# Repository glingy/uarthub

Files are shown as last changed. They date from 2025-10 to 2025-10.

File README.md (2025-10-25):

# UART Hub

This is a 6-port "null modem cable". There are six 4-signal UART channels with flow control. Each channel is connected to all six RP2040's at each USB port to allow full software configuration of which USB ports communicate on which channels. 

For example with the following configuration:
```
Channel 0: Port 0, Port 1
Channel 1: Port 0, Port 2
Channel 2: Port 1, Port 3
Channel 3: Port 1, Port 2
Channel 4: Port 0, Port 1
Channel 5: Port 0, External
```

A computer connected to USB 0 will see four USB CDC-ACM serial ports (COM ports on Windows, TTY's on Linux). They will be connected to USB 1, USB 2, USB 1, and the external pins labeled `5` respectively. Port 1 will also have four serial ports (USB 0, USB 3, USB 2, USB 0). Note that in this case there are two independent serial connections between USB 0 and 1. USB 2 will have two serial ports, USB 3 will only see one port, and USB 4 & 5 will see no serial ports. 

USB 0 will also have an additional management serial port that allows runtime configuration of which ports are associated with each channel via a terminal-based UI.

This project is not intended to work for other protocols (I2C, SPI), but the hardware should be capable of supporting I2C or SPI devices on the external pins, the RP2040 uses the same pins for I2C/SPI as it does for UART.

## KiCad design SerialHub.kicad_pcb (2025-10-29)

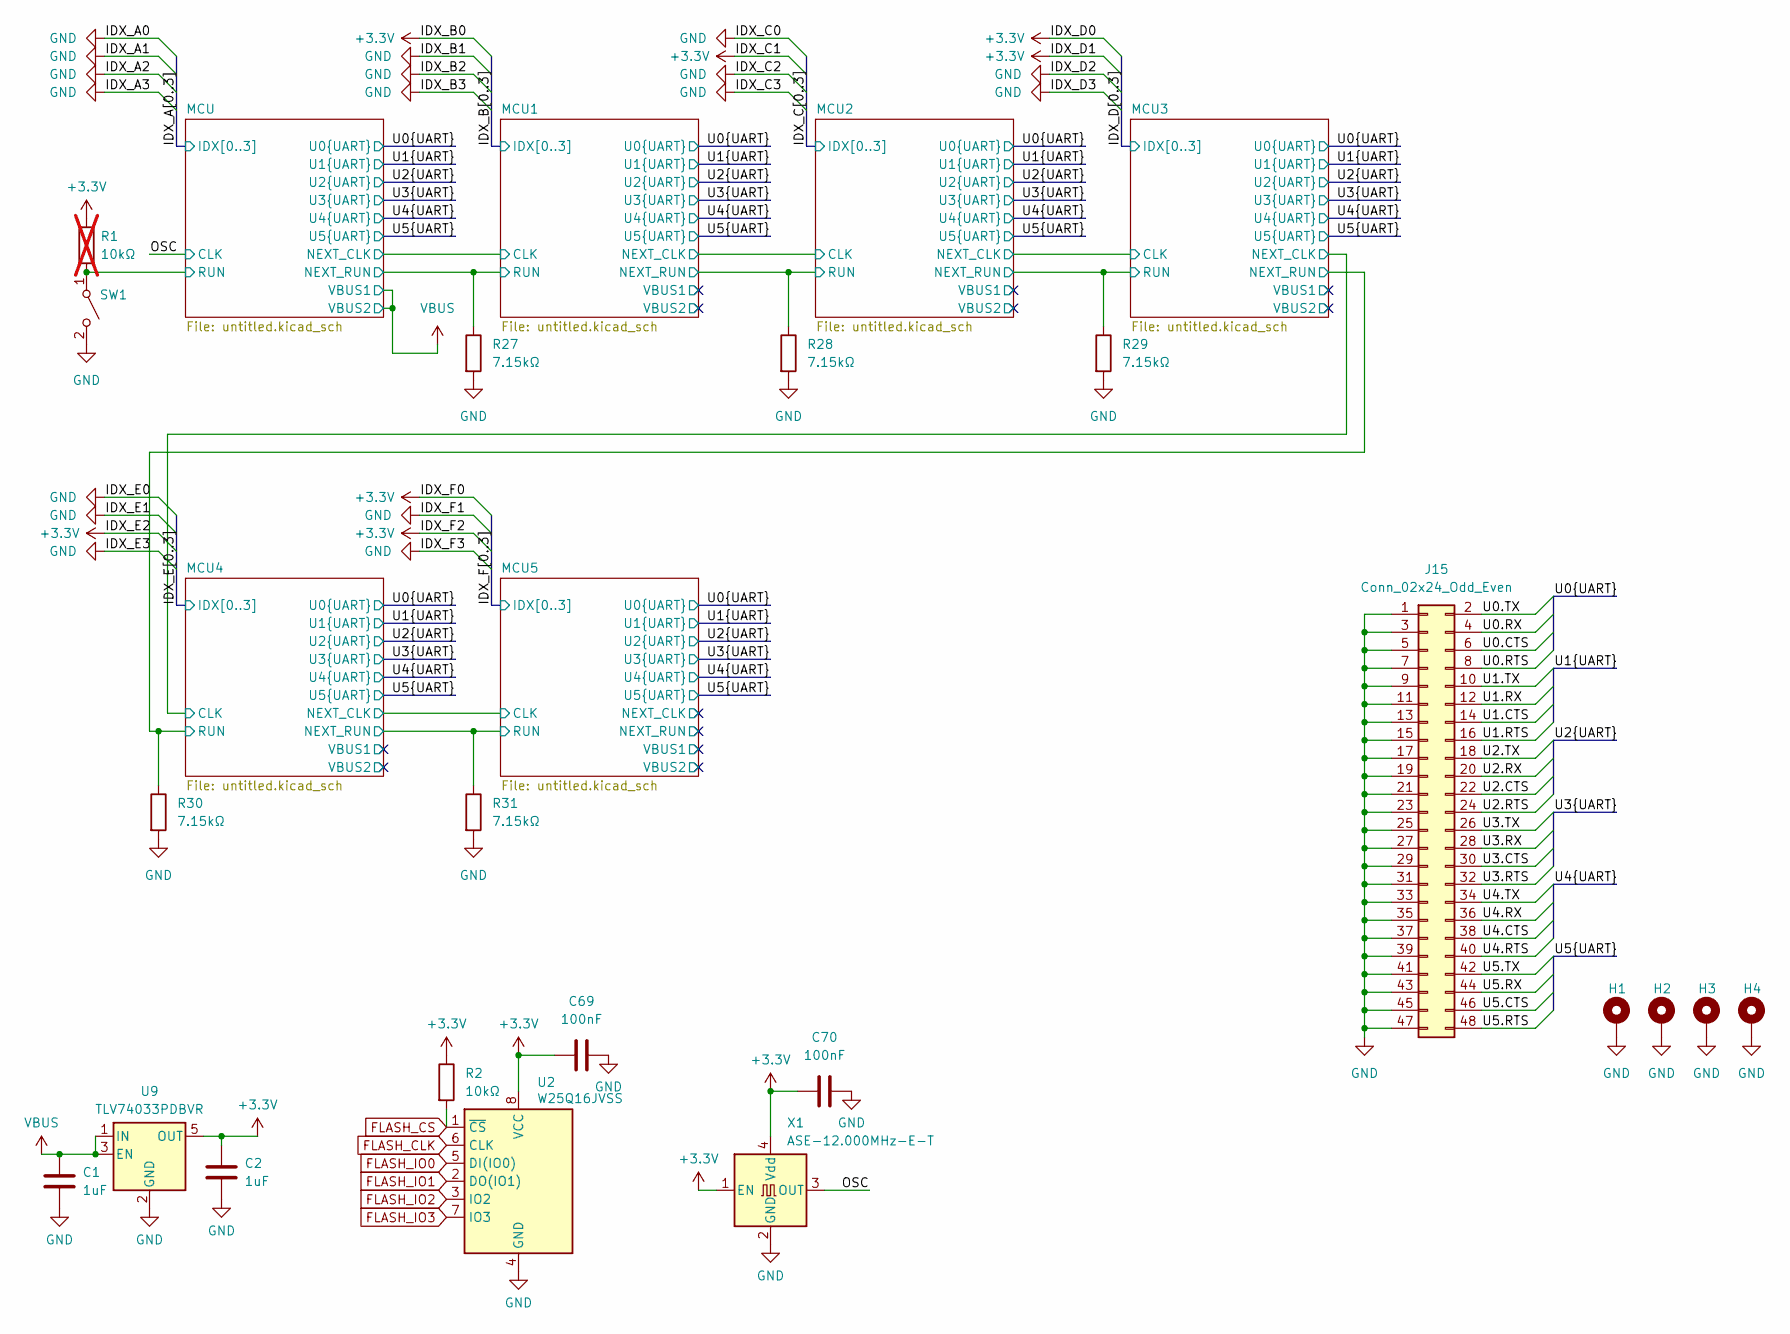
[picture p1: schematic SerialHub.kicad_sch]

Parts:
C1, C2: 1uF; C_0402_1005Metric; Digikey 399-C0402C105K9PACTUCT-ND
C69, C70: 100nF; C_0402_1005Metric; Digikey 399-C0402C105K9PACTUCT-ND
H1, H2, H3, H4: MountingHole_Pad; MountingHole_3.2mm_M3_Pad
J15: Conn_02x24_Odd_Even; PinHeader_2x24_P2.54mm_Vertical
R1: 10kΩ; R_0402_1005Metric; Digikey 311-10KJRCT-ND; not fitted
R2: 10kΩ; R_0402_1005Metric; Digikey 311-10KJRCT-ND
R27, R28, R29, R30, R31: 7.15kΩ; R_0402_1005Metric; Digikey YAG3235CT-ND
SW1: SW_SPST; SW_PUSH_6mm_H4.3mm; Digikey 2223-TS02-66-43-BK-160-LCR-D-ND
U2: W25Q16JVSS; SOIC-8_5.3x5.3mm_P1.27mm; Digikey 256-W25Q16JVSSIQTRCT-ND
U9: TLV74033PDBVR; SOT-23-5; Digikey 296-TLV74033PDBVRCT-ND
X1: ASE-12.000MHz-E-T; Oscillator_SMD_Abracon_ASE-4Pin_3.2x2.5mm; Digikey 535-ASE-12.000MHZ-E-TCT-ND

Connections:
+3.3V: C2.1, C69.1, C70.1, R1.2, R2.1, U2.8 (VCC), U9.5 (OUT), X1.1 (EN), X1.4 (Vdd); also elsewhere on the board
/MCU1/NEXT_RUN: R28.1; also elsewhere on the board
/MCU2/NEXT_RUN: R29.1; also elsewhere on the board
/MCU3/NEXT_RUN: R30.1; also elsewhere on the board
/MCU4/NEXT_RUN: R31.1; also elsewhere on the board
/MCU/NEXT_RUN: R27.1; also elsewhere on the board
/MCU/RUN: R1.1, SW1.1 (A); also elsewhere on the board
/OSC: X1.3 (OUT); also elsewhere on the board
/U0.CTS: J15.6; also elsewhere on the board
/U0.RTS: J15.8; also elsewhere on the board
/U0.RX: J15.4; also elsewhere on the board
/U0.TX: J15.2; also elsewhere on the board
/U1.CTS: J15.14; also elsewhere on the board
/U1.RTS: J15.16; also elsewhere on the board
/U1.RX: J15.12; also elsewhere on the board
/U1.TX: J15.10; also elsewhere on the board
/U2.CTS: J15.22; also elsewhere on the board
/U2.RTS: J15.24; also elsewhere on the board
/U2.RX: J15.20; also elsewhere on the board
/U2.TX: J15.18; also elsewhere on the board
/U3.CTS: J15.30; also elsewhere on the board
/U3.RTS: J15.32; also elsewhere on the board
/U3.RX: J15.28; also elsewhere on the board
/U3.TX: J15.26; also elsewhere on the board
/U4.CTS: J15.38; also elsewhere on the board
/U4.RTS: J15.40; also elsewhere on the board
/U4.RX: J15.36; also elsewhere on the board
/U4.TX: J15.34; also elsewhere on the board
/U5.CTS: J15.46; also elsewhere on the board
/U5.RTS: J15.48; also elsewhere on the board
/U5.RX: J15.44; also elsewhere on the board
/U5.TX: J15.42; also elsewhere on the board
FLASH_CLK: U2.6 (CLK); also elsewhere on the board
FLASH_CS: R2.2, U2.1 (~CS); also elsewhere on the board
FLASH_IO0: U2.5 (DI(IO0)); also elsewhere on the board
FLASH_IO1: U2.2 (DO(IO1)); also elsewhere on the board
FLASH_IO2: U2.3 (IO2); also elsewhere on the board
FLASH_IO3: U2.7 (IO3); also elsewhere on the board
VBUS: C1.1, U9.1 (IN), U9.3 (EN); also elsewhere on the board

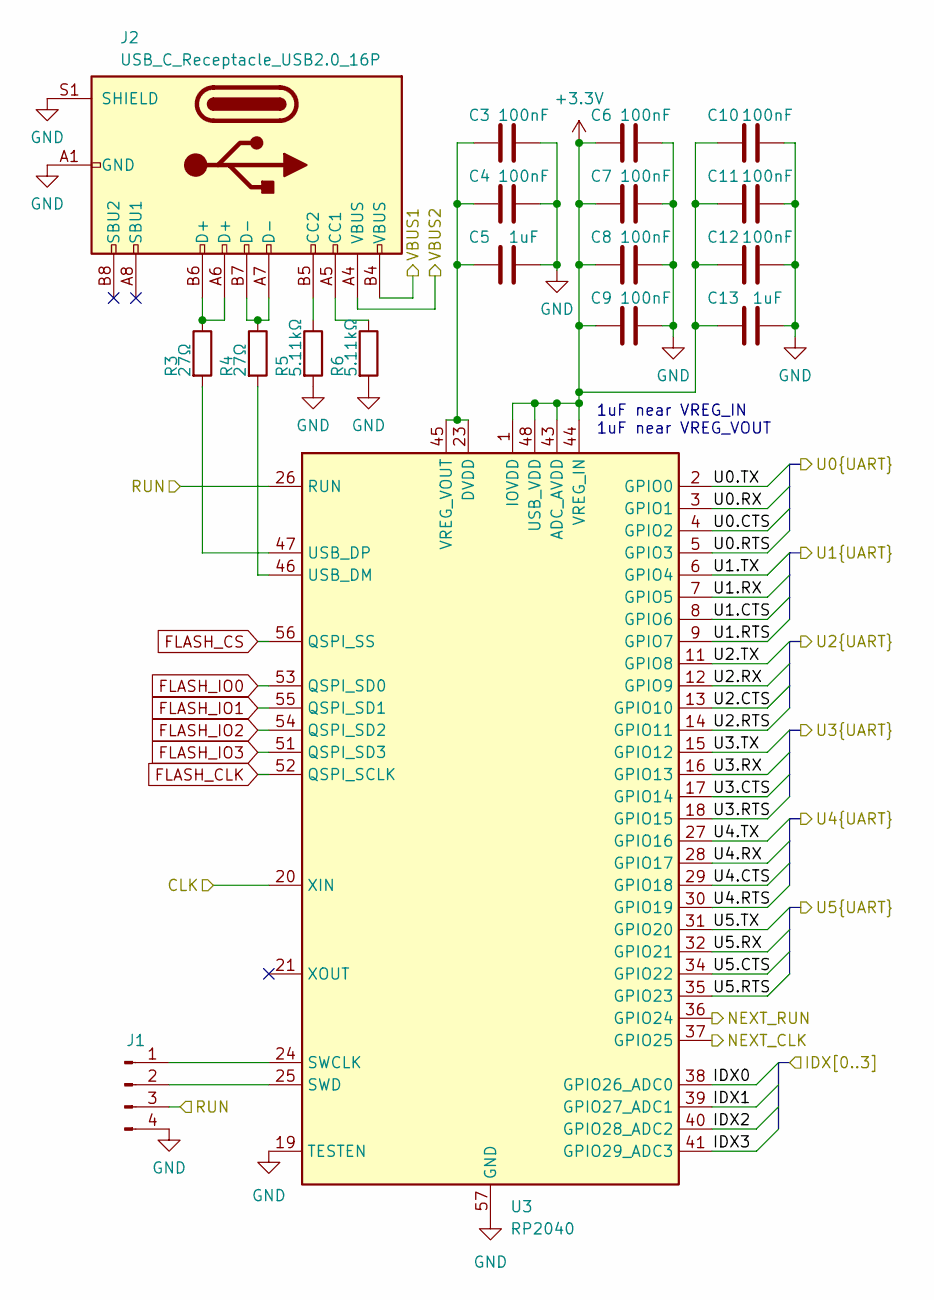
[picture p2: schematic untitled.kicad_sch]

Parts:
C3, C4, C6, C7, C8, C9, C10, C11, C12: 100nF; C_0402_1005Metric; Digikey 1276-1043-1-ND
C5, C13: 1uF; C_0402_1005Metric; Digikey 399-C0402C105K9PACTUCT-ND
J1: Conn_01x04_Pin; SaleaeTestpoint4
J2: USB_C_Receptacle_USB2.0_16P; SAMESKY_UJ20-C-H-G-SMT-1-P16-TR; Digikey 2223-UJ20-C-H-G-SMT-1-P16-TRCT-ND
R3, R4: 27Ω; R_0402_1005Metric; Digikey YAG5278CT-ND
R5, R6: 5.11kΩ; R_0402_1005Metric; Digikey RMCF0402FT5K11CT-ND
U3: RP2040; QFN-56-1EP_7x7mm_P0.4mm_EP3.2x3.2mm; Digikey 2648-SC0914(13)CT-ND

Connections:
+3.3V: C6.1, C7.1, C8.1, C9.1, C10.1, C11.1, C12.1, C13.1, U3.1 (IOVDD), U3.10 (IOVDD), U3.22 (IOVDD), U3.33 (IOVDD), U3.42 (IOVDD), U3.43 (ADC_AVDD), U3.44 (VREG_IN), U3.48 (USB_VDD), U3.49 (IOVDD); also elsewhere on the board
/MCU/NEXT_CLK: U3.37 (GPIO25); also elsewhere on the board
/MCU/NEXT_RUN: U3.36 (GPIO24); also elsewhere on the board
/MCU/RUN: J1.3, U3.26 (RUN); also elsewhere on the board
/OSC: U3.20 (XIN); also elsewhere on the board
/U0.CTS: U3.4 (GPIO2); also elsewhere on the board
/U0.RTS: U3.5 (GPIO3); also elsewhere on the board
/U0.RX: U3.3 (GPIO1); also elsewhere on the board
/U0.TX: U3.2 (GPIO0); also elsewhere on the board
/U1.CTS: U3.8 (GPIO6); also elsewhere on the board
/U1.RTS: U3.9 (GPIO7); also elsewhere on the board
/U1.RX: U3.7 (GPIO5); also elsewhere on the board
/U1.TX: U3.6 (GPIO4); also elsewhere on the board
/U2.CTS: U3.13 (GPIO10); also elsewhere on the board
/U2.RTS: U3.14 (GPIO11); also elsewhere on the board
/U2.RX: U3.12 (GPIO9); also elsewhere on the board
/U2.TX: U3.11 (GPIO8); also elsewhere on the board
/U3.CTS: U3.17 (GPIO14); also elsewhere on the board
/U3.RTS: U3.18 (GPIO15); also elsewhere on the board
/U3.RX: U3.16 (GPIO13); also elsewhere on the board
/U3.TX: U3.15 (GPIO12); also elsewhere on the board
/U4.CTS: U3.29 (GPIO18); also elsewhere on the board
/U4.RTS: U3.30 (GPIO19); also elsewhere on the board
/U4.RX: U3.28 (GPIO17); also elsewhere on the board
/U4.TX: U3.27 (GPIO16); also elsewhere on the board
/U5.CTS: U3.34 (GPIO22); also elsewhere on the board
/U5.RTS: U3.35 (GPIO23); also elsewhere on the board
/U5.RX: U3.32 (GPIO21); also elsewhere on the board
/U5.TX: U3.31 (GPIO20); also elsewhere on the board
FLASH_CLK: U3.52 (QSPI_SCLK); also elsewhere on the board
FLASH_CS: U3.56 (QSPI_SS); also elsewhere on the board
FLASH_IO0: U3.53 (QSPI_SD0); also elsewhere on the board
FLASH_IO1: U3.55 (QSPI_SD1); also elsewhere on the board
FLASH_IO2: U3.54 (QSPI_SD2); also elsewhere on the board
FLASH_IO3: U3.51 (QSPI_SD3); also elsewhere on the board
unnamed: J1.1, U3.24 (SWCLK)
unnamed: J1.2, U3.25 (SWD)
unnamed: J2.A5 (CC1), R6.1
unnamed: J2.B5 (CC2), R5.1
unnamed: J2.A6 (D+), J2.B6 (D+), R3.1
unnamed: J2.A7 (D-), J2.B7 (D-), R4.1
unnamed: R4.2, U3.46 (USB_DM)
unnamed: R3.2, U3.47 (USB_DP)
unnamed: C3.1, C4.1, C5.1, U3.23 (DVDD), U3.45 (VREG_VOUT), U3.50 (DVDD)
VBUS: J2.A4 (VBUS), J2.B4 (VBUS); also elsewhere on the board

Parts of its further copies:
C14, C15, C17, C18, C19, C20, C21, C22, C23, C25, C26, C28, C29, C30, C31, C32, C33, C34, C36, C37, C39, C40, C41, C42, C43, C44, C45, C47, C48, C50, C51, C52, C53, C54, C55, C56, C58, C59, C61, C62, C63, C64, C65, C66, C67: 100nF; C_0402_1005Metric; Digikey 1276-1043-1-ND
C16, C24, C27, C35, C38, C46, C49, C57, C60, C68: 1uF; C_0402_1005Metric; Digikey 399-C0402C105K9PACTUCT-ND
J3, J5, J7, J9, J11: Conn_01x04_Pin; SaleaeTestpoint4
J4, J6, J8, J10, J12: USB_C_Receptacle_USB2.0_16P; SAMESKY_UJ20-C-H-G-SMT-1-P16-TR; Digikey 2223-UJ20-C-H-G-SMT-1-P16-TRCT-ND
R7, R8, R11, R12, R15, R16, R19, R20, R23, R24: 27Ω; R_0402_1005Metric; Digikey YAG5278CT-ND
R9, R10, R13, R14, R17, R18, R21, R22, R25, R26: 5.11kΩ; R_0402_1005Metric; Digikey RMCF0402FT5K11CT-ND
U4, U5, U6, U7, U8: RP2040; QFN-56-1EP_7x7mm_P0.4mm_EP3.2x3.2mm; Digikey 2648-SC0914(13)CT-ND

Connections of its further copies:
+3.3V: C17.1, C18.1, C19.1, C20.1, C21.1, C22.1, C23.1, C24.1, C28.1, C29.1, C30.1, C31.1, C32.1, C33.1, C34.1, C35.1, C39.1, C40.1, C41.1, C42.1, C43.1, C44.1, C45.1, C46.1, C50.1, C51.1, C52.1, C53.1, C54.1, C55.1, C56.1, C57.1, C61.1, C62.1, C63.1, C64.1, C65.1, C66.1, C67.1, C68.1, U4.1 (IOVDD), U4.10 (IOVDD), U4.22 (IOVDD), U4.33 (IOVDD), U4.38 (GPIO26_ADC0), U4.42 (IOVDD), U4.43 (ADC_AVDD), U4.44 (VREG_IN), U4.48 (USB_VDD), U4.49 (IOVDD), U5.1 (IOVDD), U5.10 (IOVDD), U5.22 (IOVDD), U5.33 (IOVDD), U5.39 (GPIO27_ADC1), U5.42 (IOVDD), U5.43 (ADC_AVDD), U5.44 (VREG_IN), U5.48 (USB_VDD), U5.49 (IOVDD), U6.1 (IOVDD), U6.10 (IOVDD), U6.22 (IOVDD), U6.33 (IOVDD), U6.38 (GPIO26_ADC0), U6.39 (GPIO27_ADC1), U6.42 (IOVDD), U6.43 (ADC_AVDD), U6.44 (VREG_IN), U6.48 (USB_VDD), U6.49 (IOVDD), U7.1 (IOVDD), U7.10 (IOVDD), U7.22 (IOVDD), U7.33 (IOVDD), U7.40 (GPIO28_ADC2), U7.42 (IOVDD), U7.43 (ADC_AVDD), U7.44 (VREG_IN), U7.48 (USB_VDD), U7.49 (IOVDD), U8.1 (IOVDD), U8.10 (IOVDD), U8.22 (IOVDD), U8.33 (IOVDD), U8.38 (GPIO26_ADC0), U8.40 (GPIO28_ADC2), U8.42 (IOVDD), U8.43 (ADC_AVDD), U8.44 (VREG_IN), U8.48 (USB_VDD), U8.49 (IOVDD); also elsewhere on the board
/MCU1/NEXT_CLK: U4.37 (GPIO25), U5.20 (XIN)
/MCU1/NEXT_RUN: J5.3, U4.36 (GPIO24), U5.26 (RUN); also elsewhere on the board
/MCU1/VBUS1: J4.B4 (VBUS)
/MCU1/VBUS2: J4.A4 (VBUS)
/MCU2/NEXT_CLK: U5.37 (GPIO25), U6.20 (XIN)
/MCU2/NEXT_RUN: J7.3, U5.36 (GPIO24), U6.26 (RUN); also elsewhere on the board
/MCU2/VBUS1: J6.B4 (VBUS)
/MCU2/VBUS2: J6.A4 (VBUS)
/MCU3/NEXT_CLK: U6.37 (GPIO25), U7.20 (XIN)
/MCU3/NEXT_RUN: J9.3, U6.36 (GPIO24), U7.26 (RUN); also elsewhere on the board
/MCU3/VBUS1: J8.B4 (VBUS)
/MCU3/VBUS2: J8.A4 (VBUS)
/MCU4/NEXT_CLK: U7.37 (GPIO25), U8.20 (XIN)
/MCU4/NEXT_RUN: J11.3, U7.36 (GPIO24), U8.26 (RUN); also elsewhere on the board
/MCU4/VBUS1: J10.B4 (VBUS)
/MCU4/VBUS2: J10.A4 (VBUS)
/MCU5/NEXT_CLK: U8.37 (GPIO25)
/MCU5/NEXT_RUN: U8.36 (GPIO24)
/MCU5/VBUS1: J12.B4 (VBUS)
/MCU5/VBUS2: J12.A4 (VBUS)
/MCU/NEXT_CLK: U4.20 (XIN); also elsewhere on the board
/MCU/NEXT_RUN: J3.3, U4.26 (RUN); also elsewhere on the board
/U0.CTS: U4.4 (GPIO2), U5.4 (GPIO2), U6.4 (GPIO2), U7.4 (GPIO2), U8.4 (GPIO2); also elsewhere on the board
/U0.RTS: U4.5 (GPIO3), U5.5 (GPIO3), U6.5 (GPIO3), U7.5 (GPIO3), U8.5 (GPIO3); also elsewhere on the board
/U0.RX: U4.3 (GPIO1), U5.3 (GPIO1), U6.3 (GPIO1), U7.3 (GPIO1), U8.3 (GPIO1); also elsewhere on the board
/U0.TX: U4.2 (GPIO0), U5.2 (GPIO0), U6.2 (GPIO0), U7.2 (GPIO0), U8.2 (GPIO0); also elsewhere on the board
/U1.CTS: U4.8 (GPIO6), U5.8 (GPIO6), U6.8 (GPIO6), U7.8 (GPIO6), U8.8 (GPIO6); also elsewhere on the board
/U1.RTS: U4.9 (GPIO7), U5.9 (GPIO7), U6.9 (GPIO7), U7.9 (GPIO7), U8.9 (GPIO7); also elsewhere on the board
/U1.RX: U4.7 (GPIO5), U5.7 (GPIO5), U6.7 (GPIO5), U7.7 (GPIO5), U8.7 (GPIO5); also elsewhere on the board
/U1.TX: U4.6 (GPIO4), U5.6 (GPIO4), U6.6 (GPIO4), U7.6 (GPIO4), U8.6 (GPIO4); also elsewhere on the board
/U2.CTS: U4.13 (GPIO10), U5.13 (GPIO10), U6.13 (GPIO10), U7.13 (GPIO10), U8.13 (GPIO10); also elsewhere on the board
/U2.RTS: U4.14 (GPIO11), U5.14 (GPIO11), U6.14 (GPIO11), U7.14 (GPIO11), U8.14 (GPIO11); also elsewhere on the board
/U2.RX: U4.12 (GPIO9), U5.12 (GPIO9), U6.12 (GPIO9), U7.12 (GPIO9), U8.12 (GPIO9); also elsewhere on the board
/U2.TX: U4.11 (GPIO8), U5.11 (GPIO8), U6.11 (GPIO8), U7.11 (GPIO8), U8.11 (GPIO8); also elsewhere on the board
/U3.CTS: U4.17 (GPIO14), U5.17 (GPIO14), U6.17 (GPIO14), U7.17 (GPIO14), U8.17 (GPIO14); also elsewhere on the board
/U3.RTS: U4.18 (GPIO15), U5.18 (GPIO15), U6.18 (GPIO15), U7.18 (GPIO15), U8.18 (GPIO15); also elsewhere on the board
/U3.RX: U4.16 (GPIO13), U5.16 (GPIO13), U6.16 (GPIO13), U7.16 (GPIO13), U8.16 (GPIO13); also elsewhere on the board
/U3.TX: U4.15 (GPIO12), U5.15 (GPIO12), U6.15 (GPIO12), U7.15 (GPIO12), U8.15 (GPIO12); also elsewhere on the board
/U4.CTS: U4.29 (GPIO18), U5.29 (GPIO18), U6.29 (GPIO18), U7.29 (GPIO18), U8.29 (GPIO18); also elsewhere on the board
/U4.RTS: U4.30 (GPIO19), U5.30 (GPIO19), U6.30 (GPIO19), U7.30 (GPIO19), U8.30 (GPIO19); also elsewhere on the board
/U4.RX: U4.28 (GPIO17), U5.28 (GPIO17), U6.28 (GPIO17), U7.28 (GPIO17), U8.28 (GPIO17); also elsewhere on the board
/U4.TX: U4.27 (GPIO16), U5.27 (GPIO16), U6.27 (GPIO16), U7.27 (GPIO16), U8.27 (GPIO16); also elsewhere on the board
/U5.CTS: U4.34 (GPIO22), U5.34 (GPIO22), U6.34 (GPIO22), U7.34 (GPIO22), U8.34 (GPIO22); also elsewhere on the board
/U5.RTS: U4.35 (GPIO23), U5.35 (GPIO23), U6.35 (GPIO23), U7.35 (GPIO23), U8.35 (GPIO23); also elsewhere on the board
/U5.RX: U4.32 (GPIO21), U5.32 (GPIO21), U6.32 (GPIO21), U7.32 (GPIO21), U8.32 (GPIO21); also elsewhere on the board
/U5.TX: U4.31 (GPIO20), U5.31 (GPIO20), U6.31 (GPIO20), U7.31 (GPIO20), U8.31 (GPIO20); also elsewhere on the board
FLASH_CLK: U4.52 (QSPI_SCLK), U5.52 (QSPI_SCLK), U6.52 (QSPI_SCLK), U7.52 (QSPI_SCLK), U8.52 (QSPI_SCLK); also elsewhere on the board
FLASH_CS: U4.56 (QSPI_SS), U5.56 (QSPI_SS), U6.56 (QSPI_SS), U7.56 (QSPI_SS), U8.56 (QSPI_SS); also elsewhere on the board
FLASH_IO0: U4.53 (QSPI_SD0), U5.53 (QSPI_SD0), U6.53 (QSPI_SD0), U7.53 (QSPI_SD0), U8.53 (QSPI_SD0); also elsewhere on the board
FLASH_IO1: U4.55 (QSPI_SD1), U5.55 (QSPI_SD1), U6.55 (QSPI_SD1), U7.55 (QSPI_SD1), U8.55 (QSPI_SD1); also elsewhere on the board
FLASH_IO2: U4.54 (QSPI_SD2), U5.54 (QSPI_SD2), U6.54 (QSPI_SD2), U7.54 (QSPI_SD2), U8.54 (QSPI_SD2); also elsewhere on the board
FLASH_IO3: U4.51 (QSPI_SD3), U5.51 (QSPI_SD3), U6.51 (QSPI_SD3), U7.51 (QSPI_SD3), U8.51 (QSPI_SD3); also elsewhere on the board
unnamed: J3.1, U4.24 (SWCLK)
unnamed: J3.2, U4.25 (SWD)
unnamed: J4.A5 (CC1), R10.1
unnamed: J4.B5 (CC2), R9.1
unnamed: J4.A6 (D+), J4.B6 (D+), R7.1
unnamed: J4.A7 (D-), J4.B7 (D-), R8.1
unnamed: J5.1, U5.24 (SWCLK)
unnamed: J5.2, U5.25 (SWD)
unnamed: J6.A5 (CC1), R14.1
unnamed: J6.B5 (CC2), R13.1
unnamed: J6.A6 (D+), J6.B6 (D+), R11.1
unnamed: J6.A7 (D-), J6.B7 (D-), R12.1
unnamed: J7.1, U6.24 (SWCLK)
unnamed: J7.2, U6.25 (SWD)
unnamed: J8.A5 (CC1), R18.1
unnamed: J8.B5 (CC2), R17.1
unnamed: J8.A6 (D+), J8.B6 (D+), R15.1
unnamed: J8.A7 (D-), J8.B7 (D-), R16.1
unnamed: J9.1, U7.24 (SWCLK)
unnamed: J9.2, U7.25 (SWD)
unnamed: J10.A5 (CC1), R22.1
unnamed: J10.B5 (CC2), R21.1
unnamed: J10.A6 (D+), J10.B6 (D+), R19.1
unnamed: J10.A7 (D-), J10.B7 (D-), R20.1
unnamed: J11.1, U8.24 (SWCLK)
unnamed: J11.2, U8.25 (SWD)
unnamed: J12.A5 (CC1), R26.1
unnamed: J12.B5 (CC2), R25.1
unnamed: J12.A6 (D+), J12.B6 (D+), R23.1
unnamed: J12.A7 (D-), J12.B7 (D-), R24.1
unnamed: R8.2, U4.46 (USB_DM)
unnamed: R7.2, U4.47 (USB_DP)
unnamed: C14.1, C15.1, C16.1, U4.23 (DVDD), U4.45 (VREG_VOUT), U4.50 (DVDD)
unnamed: R12.2, U5.46 (USB_DM)
unnamed: R11.2, U5.47 (USB_DP)
unnamed: C25.1, C26.1, C27.1, U5.23 (DVDD), U5.45 (VREG_VOUT), U5.50 (DVDD)
unnamed: R16.2, U6.46 (USB_DM)
unnamed: R15.2, U6.47 (USB_DP)
unnamed: C36.1, C37.1, C38.1, U6.23 (DVDD), U6.45 (VREG_VOUT), U6.50 (DVDD)
unnamed: R20.2, U7.46 (USB_DM)
unnamed: R19.2, U7.47 (USB_DP)
unnamed: C47.1, C48.1, C49.1, U7.23 (DVDD), U7.45 (VREG_VOUT), U7.50 (DVDD)
unnamed: R24.2, U8.46 (USB_DM)
unnamed: R23.2, U8.47 (USB_DP)
unnamed: C58.1, C59.1, C60.1, U8.23 (DVDD), U8.45 (VREG_VOUT), U8.50 (DVDD)

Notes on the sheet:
1uF near VREG_IN 1uF near VREG_VOUT

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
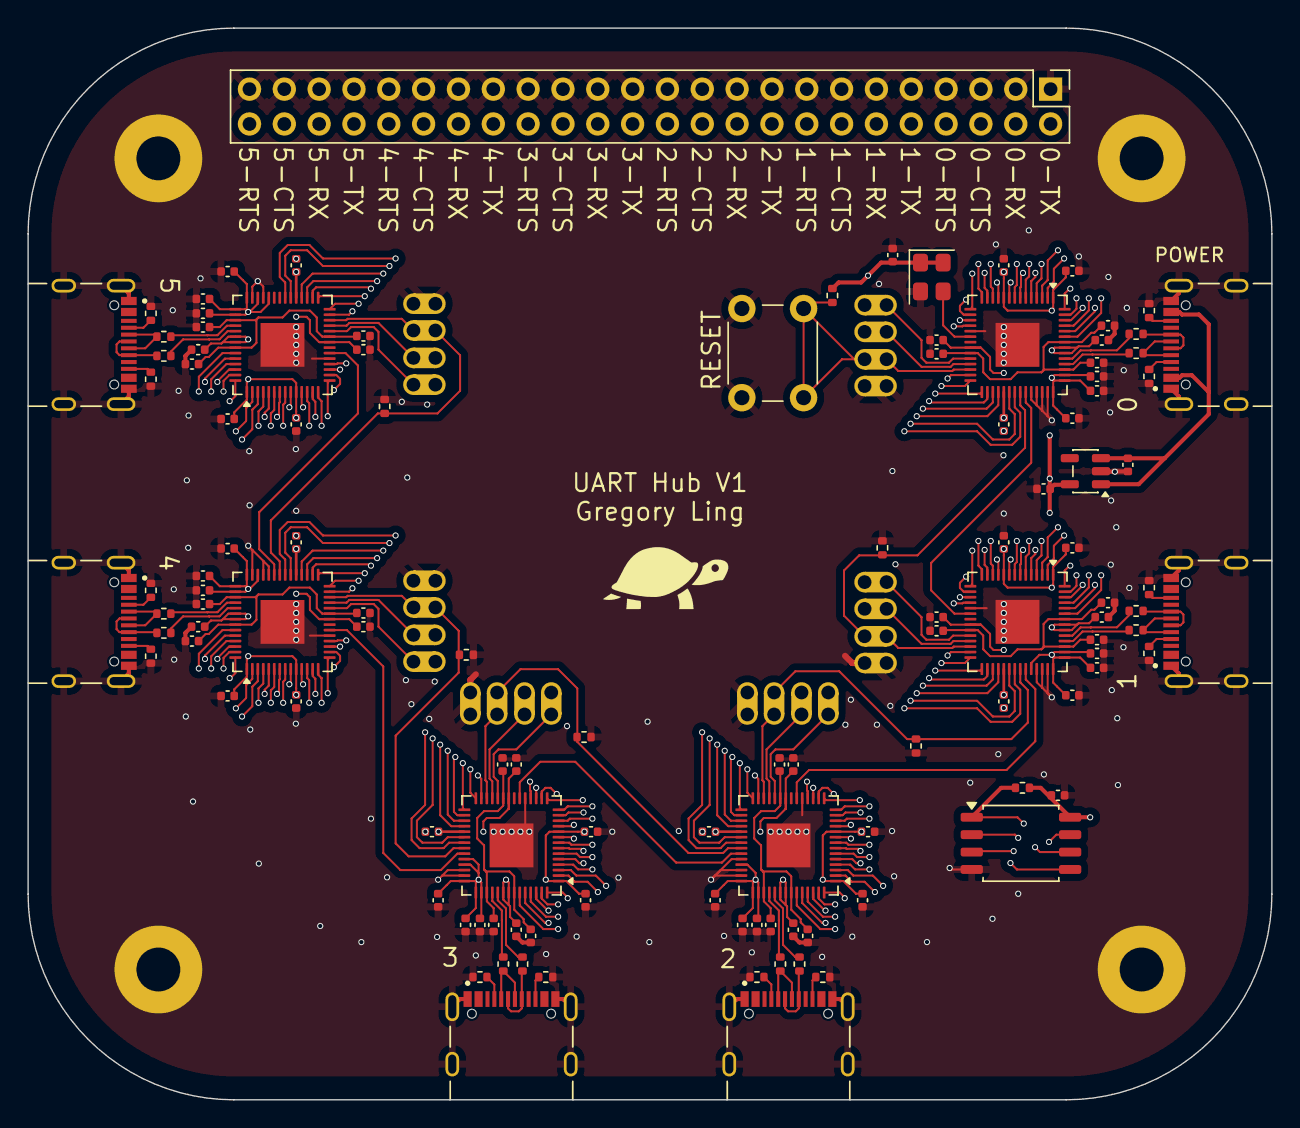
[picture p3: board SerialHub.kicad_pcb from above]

Board: 4 copper layers, 90.7 x 78.2 mm, 128 parts (0 on the bottom side), 99 nets.
